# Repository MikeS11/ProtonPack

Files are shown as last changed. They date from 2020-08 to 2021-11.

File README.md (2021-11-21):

[][contributors-url]
[][forks-url]
[][stars-url]
[][issues-url]
[][license-url]
[][Twitter-url]

<!-- PROJECT LOGO -->
<br />
<p align="center">
  <a href="https://github.com/MikeS11/ProtonPack">
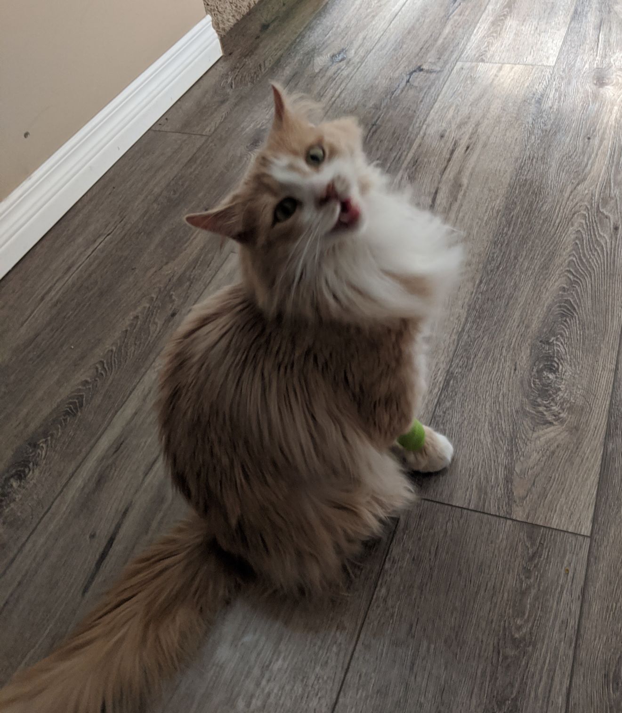
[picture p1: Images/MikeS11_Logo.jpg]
    
  </a>

  <h3 align="center">GhostKitty Proton Pack</h3>

  <p align="center">
  This is my contribution to the GB community. This project adds a bit more movie / game accuracy but also a little fun :)

<!-- TABLE OF CONTENTS -->
## Table of Contents

* [About the Project](#about-the-project)
  * [Built With](#Build-Requirements)
* [Getting Started](#getting-started)
  * [Prerequisites](#prerequisites)
  * [Wand Configuration](#wand-configuration)  
* [License](#license)
* [Contact](#contact)
* [Acknowledgements](#acknowledgements)

<!-- ABOUT THE PROJECT -->
## About The Project

<div align="center">
  YouTube Video<br /> 
  <a href="https://www.youtube.com/watch?v=9ePM4p-J3tE">GhostKitty Proton Pack</a>  
  
Original Prototype <br />
Prototype</p>

Afterlife Cyclotron 40 segment LED ring<br /> 
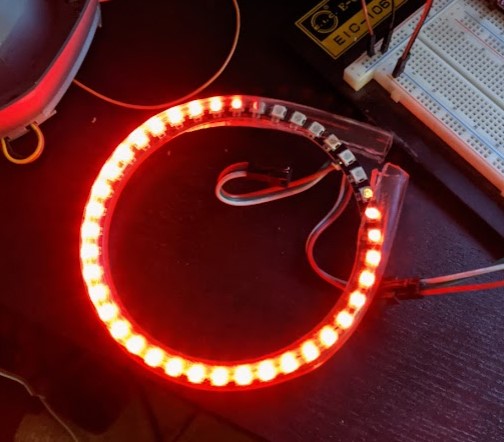
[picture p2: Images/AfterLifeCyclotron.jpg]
Prototype
</p>
</div>

I want this to be a source for anyone to use to create their own proton pack kits for as cheap as possible and still include all the features for a rumble motor, 2 firing mechanisms, all functioning LEDs in the wand, pack themes, full 28 segment bar graph, and an output for a vent kit.

**Current Themes for the pack:**
* []() Movie
* []() Stasis / Afterlife 
* []() Slime
* []() Meson
* []() Christmas!
* []() *Future* Halloween

### Getting Started

### Build Requirements:

* []() 1 - Arduino Nano (Amazon)  
* []() 1 - DFPlayer Mini (Be aware that some of the knock offs do not perform correctly, reference to the busy pin may not work) (Digikey Only)
* []() 1 - Any amplifing circuit (Currently testing an Adafruit Stereo 20W Class D Audio Amplifier - MAX9744)  (Amazon, Digikey)
* []() 1 - LED Matrix Driver - HT16K33 Breakout (for the bar graph) (Amazon, Digikey)
* []() 1 - 28 segment bargraph (barmeter.com, ebay is your best option)
* []() 1 - Pack of neopixels or equivalent WS2812B ( Vent and wand LEDs) (Amazon)
* []() 1 - LED strip (Powercell)  (Amazon)
* []() 1 - Adafruit Jewel - Wand Tip (WAs looking at the Pixie but there is a concern of its overhead requirements when working with normal WS2812B's, and they can not be chained together with WS2812B's) (Amazon, Digikey)
* []() 1 - 40 Segment LED ring or LED strip (WS2812B's) - Afterlife Cyclotron LED
* []() Pack of 24 awg stranded cable (Amazon) - To keep things clean you might want to look at ribbon cables or multi conductor cables. 
* []() For circuit noise filtering, I would add a 1000uF electrolytic capacitors closes to the neopixels, and a 470 Ohm resistor before the first led of the strip (This is recommended by Adafruit as well). I would recommend one 1000uF capacitor for the wand to filter out noise from both the bargraph and the neopixels. (See Diagram)
* []() If you are printing the PCB you will need a RJ45 Connector, 2.54mm JST Connectors, 2.54mm Dupont Connectors, 1 MP1584EN Buck Converter, 7805 Voltage regulator, 2 1k Ohm resistors, and some 0.1 uF and 0.33 uF ceramic capacitors. Additionally for the wand, 1000uF capacitor, a 1N4001 diode and a transistor.

### Prerequisites

You are going to need to install the following libraries:

**For the Audio DFPlayer Player:**
* []() SoftwareSerial.h
* []() DFPlayerMini_Fast.h

**For the WS2812B / NeoPixel LEDs**
* []() Adafruit_NeoPixel.h

**Custom Libraries for the Powercell / Cyclotron / Bargraph Animiations**
* []() GBLEDPatternsJewel.h
* []() BGSequence.h

**Sound Files for the DFPlayer or Alternative Player**

<a href="https://mega.nz/file/R5sWzCha#zm4DIskyvmF08JNp8MnOAEqCDmNe2MSCN6wtFMExKlU">Here are some sound files I found online or mixed myself</a>

### Wand Configuration

<p align="center">
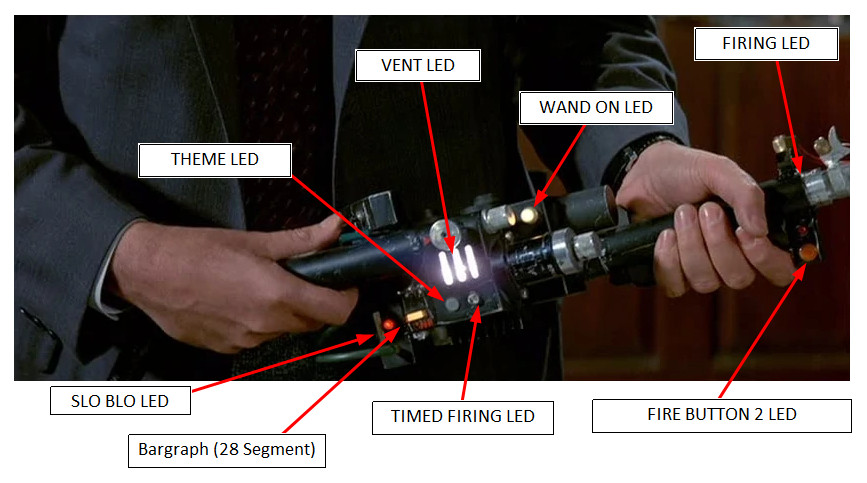
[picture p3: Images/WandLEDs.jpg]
Wand LEDs
</p>
<p align="center">
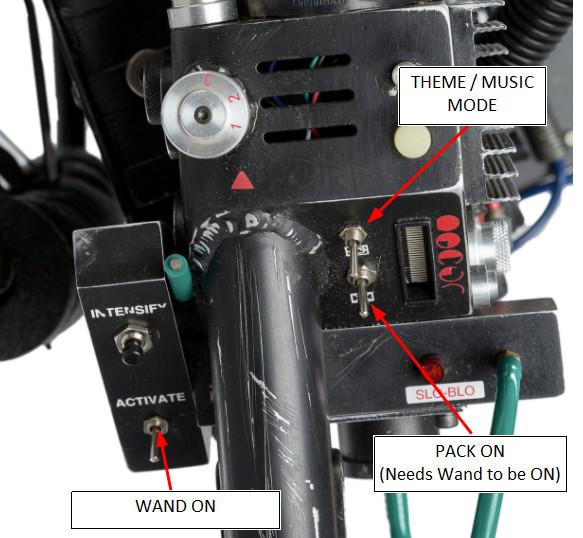
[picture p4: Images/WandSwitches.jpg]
Wand Switches
</p>
<!-- CONTRIBUTING -->
## Contributing

Contributions are what make the open source community such an amazing place to be learn, inspire, and create. Any contributions you make are **greatly appreciated**.

1. Fork the Project
2. Create your Feature Branch (`git checkout -b feature/AmazingFeature`)
3. Commit your Changes (`git commit -m 'Add some AmazingFeature'`)
4. Push to the Branch (`git push origin feature/AmazingFeature`)
5. Open a Pull Request

<!-- LICENSE -->
## License

Distributed under the MIT License. See `LICENSE` for more information.

<!-- CONTACT -->
## Contact

Mike Simone - [@mikesimone3](https://twitter.com/mikesimone3) 

Project Link: [https://github.com/MikeS11/ProtonPack](https://github.com/MikeS11/ProtonPack)

<!-- ACKNOWLEDGEMENTS -->
## Acknowledgements

* []() Eric Banker for the for the wonder work completed on his Arduino project. (a couple of his functions are referenced in this project) 
* []()
* []()

<!-- MARKDOWN LINKS & IMAGES -->
<!-- https://www.markdownguide.org/basic-syntax/#reference-style-links -->
[contributors-shield]: https://img.shields.io/github/contributors/MikeS11/ProtonPack.svg?style=flat-square
[contributors-url]: https://github.com/MikeS11/ProtonPack/graphs/contributors
[forks-shield]: https://img.shields.io/github/forks/MikeS11/ProtonPack.svg?style=flat-square
[forks-url]: https://github.com/MikeS11/ProtonPack/network/members
[stars-shield]: https://img.shields.io/github/stars/MikeS11/ProtonPack.svg?style=flat-square
[stars-url]: https://github.com/MikeS11/ProtonPack/stargazers
[issues-shield]: https://img.shields.io/github/issues/MikeS11/ProtonPack.svg?style=flat-square
[issues-url]: https://github.com/MikeS11/ProtonPack/issues
[license-shield]: https://img.shields.io/github/license/MikeS11/ProtonPack.svg?style=flat-square
[license-url]: https://github.com/MikeS11/ProtonPack/blob/master/LICENSE.txt
[twitter-shield]: https://img.shields.io/badge/-Twitter-black.svg?style=flat-square&logo=Twitter&colorB=555
[twitter-url]: https://Twitter.com/mikesimone3
[product-screenshot]: images/screenshot.png

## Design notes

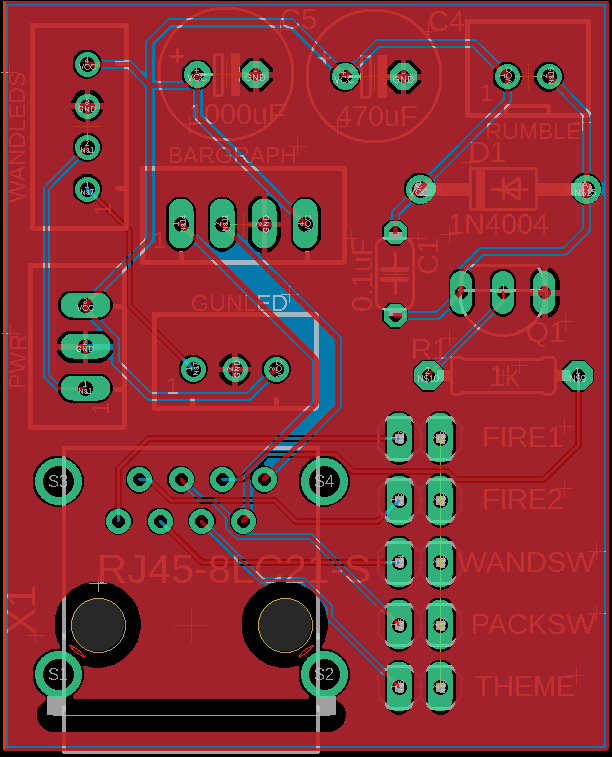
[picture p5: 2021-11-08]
Eagle PCB/WandPCB.png

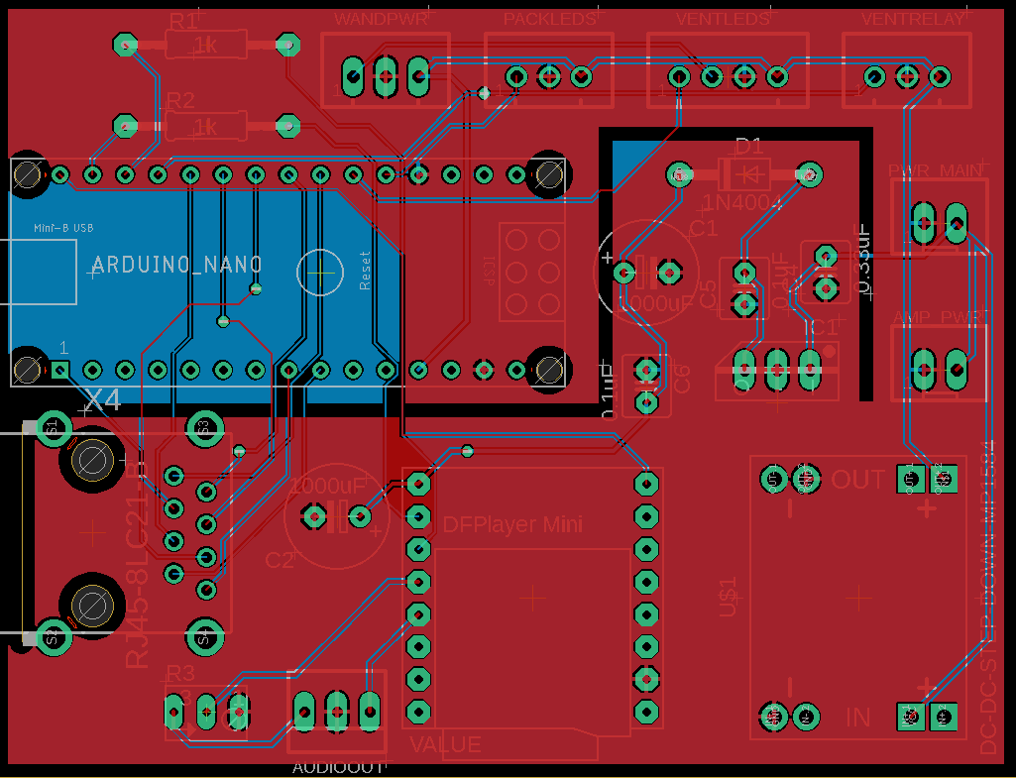
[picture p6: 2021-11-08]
Eagle PCB/PackPCB.png

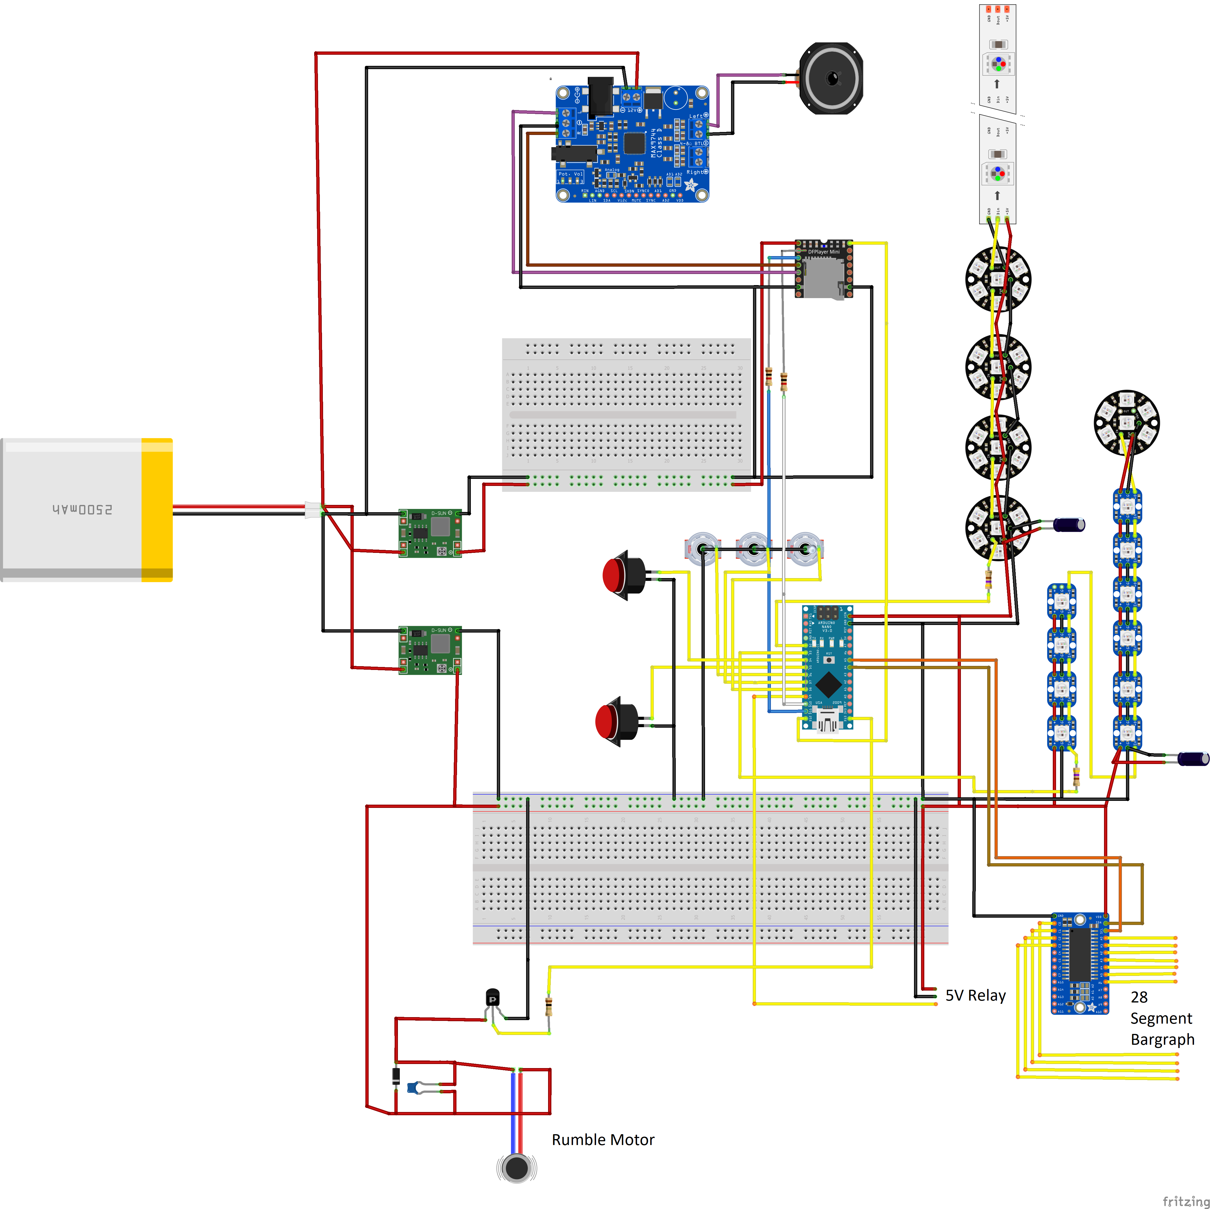
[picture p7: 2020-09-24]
Diagram/ProtonPack2020_bb1.png

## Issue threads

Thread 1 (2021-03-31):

Thanks! And a couple of small bargraph bugs...

prodestrian, 2021-03-31:
Hi! Found this repo on the Facebook Group a while back and finally getting around to doing some of the pack electronics.

I started writing a library to handle a 28-segment bargraph controlled by a HT16K33 when I remembered you'd basically already done all the work, so I brought yours in and I've started testing it. So far so good, you've easily saved me days of work here, so thankyou! :smile:

Just a couple of little things I noticed...

https://github.com/MikeS11/ProtonPack/blob/ab19a8d30ab484f0a8a88561ca24bb286b1c2d76/Source/Libraries/GB_Bargraph_Sequence/BGSequence.cpp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
In my local copy of the library, I've modified this so that the address can be passed in. My breakout board is actually on `0x72` (because it's salvaged from another project and I haven't yet desoldered the jumper), so this lets me control it from outside the library:
```c++
void BGSequence::BGSeq(uint8_t addr)
{
  /*
     Initiate the HT16K33
  */
  bargraph.init(addr);
```

https://github.com/MikeS11/ProtonPack/blob/ab19a8d30ab484f0a8a88561ca24bb286b1c2d76/Source/Libraries/GB_Bargraph_Sequence/BGSequence.cpp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
The sequenceStart animation causes my 28th pixel to flash for just a second before the animation starts at the other end. Changing `IndexSegment` from `27` to `0` seems to fix it.

https://github.com/MikeS11/ProtonPack/blob/ab19a8d30ab484f0a8a88561ca24bb286b1c2d76/Source/Libraries/ht16k33-arduino-master/HT16K33.cpp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
I noticed that on startup/reset random pixels on the bargraph would flash for a split second, so I borrowed the code from the Adafruit LEDBackpack library which resets the "garbage" before turning the LEDs on. Problem solved!
```c++
  // internal RAM powers up with garbage/random values.
  // ensure internal RAM is cleared before turning on display
  // this ensures that no garbage pixels show up on the display
  // when it is turned on.
  clear();
  write();

  // set blink off + brightness all the way up
  setBlink(HT16K33_BLINK_OFF);
  setBrightness(15);
```

https://github.com/MikeS11/ProtonPack/blob/ab19a8d30ab484f0a8a88561ca24bb286b1c2d76/Source/Libraries/GB_Bargraph_Sequence/BGSequence.cpp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
I changed this to just use the HT16K33 `clear()` function which does basically the same thing.
```c++
void BGSequence::clearLEDs()
{
  bargraph.clear();
  bargraph.write();
}
```

That's all I have for now, I may end up forking and refactoring the code to fit better in my project's codebase, but if I get a chance I'll see if I can submit a PR at the same time. I can also see some room for simplification around the place, but we'll see if I get time to look into it.

Thanks again for releasing this! :grin: :trophy:

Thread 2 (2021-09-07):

What exactly is this 5v relay used for in the diagram on the bottom right next to the bargraph? Thanks!

ytineres, 2021-09-07:

MikeS11, 2021-09-07:
It's used for an expandable smoke kit and triggers a relay to power it's
operation.

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

ytineres, 2021-09-07:
Thanks so much! saves me a step of adding it in later.

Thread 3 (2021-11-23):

28 segment bargraph help

seansz28, 2021-11-23:
is there a diagram how to solder the 28 segment bar graph to the breakout board

semix79, 2022-03-17:
I have Problems to run the Bargraph. I soldered like in the Youtube Video from Wholesome Joe. But it doesn´t fuction. Do i must chance something in the Code? I tested with different Arduino nanos, and 2 different ht16k33 Chips. No function from the Bargraph. The Bargraph Leds are okay.

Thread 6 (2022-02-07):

aiuto

nonsochenomemettere1111111, 2022-02-07:
Ciao Mike , mi piacerebbe usare il tuo progetto e volevo chiederti i file audio vanno messi tutti su sd card ? è da rispettare l'ordine che hai postato ? i due pulsanti a cosa servono? e possibile caricare ache la canzone di ghostbusters ? se si come ?

nonsochenomemettere1111111, 2022-02-13:
Dal video di mikes11 sembra che funziona !!! Come mai ?

semix79, 2022-02-13:
I find something out. What size of sd card do you Use? With a 2gb card the songs work.  Use  001, 002, 003, 004 and so on for the numbers in the 01 folder. But the issue with the Sound is still there :(

nonsochenomemettere1111111, 2022-02-13:
Uso una sd da 2gb  .... infatti le canzoni funzionano anche a me... ma gi effetti compreso quello dello stato non funziona .... come si cambiano le modalità film, christmas ecc... ?

semix79, 2022-02-17:
I have solved the Problem! It realy depends on the dfplayer! You need the one who is manufactured by dfrobot! Then it works perfect! I tested 4 different chips. Only the dfrobot works.

nonsochenomemettere1111111, 2022-02-17:
Puoi mandarmi il link per acquistare quello giusto?

semix79, 2022-02-17:
Digikey.de

nonsochenomemettere1111111, 2022-02-17:
Grazie   grazie

nonsochenomemettere1111111, 2022-02-23:
Grazie all'aiuto di semix79  ho risolto anche  io ,montando dfplayer mini originale df roboot ...una domanda a semix79... le canzoni che si possono aggiungere vanno messe nel formato mp3 nella cartella 01 ? Perché mi succede che se le metto sulla cartella 01 come accendo esegue subito brani mp3 .... qli effetti vanno lasciati nella cartella mp3 ?  Grazie in anticipo per il tuo aiuto ....

semix79, 2022-02-23:
Gerne. :) Es ist egal ob mp3 oder wav. Die Trackbeschriftung hast du richtig? Dreistellig bei den Songs und Vierstellig bei den Effekten im mp3 ordner. Lösche mal die Sd Karte und spiele alles noch einmal gleichzeitig auf die Karte.

nonsochenomemettere1111111, 2022-02-23:
Ok ok .. non avevo capito... quindi la cartella 01 può essere cancellata o lasciata vuota ?

semix79, 2022-02-23:
In den 01 ordner kommen die Lieder

nonsochenomemettere1111111, 2022-02-23:
Ok grazie grazie  del tempo dedicato lo zaino protonico come l'hai realizzato con stampante 3d ? Il progetto dove l'hai preso ?

nonsochenomemettere1111111, 2022-02-27:
Quali sono le funzioni specifiche degli interruttori e dei pulsanti ? C'è xuna sequenza di accensione da rispettare ? Come metto  i file audio rinominandoli in 001,002 ecc vengono riprodotti come accendo ... perché?

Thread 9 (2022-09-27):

Error in trace placement on pack PCB

GForce2010, 2022-09-27:
Firstly, thanks for sharing your designs and code, very helpful.

I've just downloaded the PCB files and when I was trying to work out how everything connected on the board I found that two traces appear to be overlapping.

The trace from D2 to PackLEDA is overlapping with the trace from D9 to VentRelayA just below he WANDPWR terminal block.

meltman, 2022-09-27:
If you correct the issues, mind exporting gerber files and doing a PR? Lol, looks like halloween is on the horizon.

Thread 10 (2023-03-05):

fuzzy on some details (pcb)

tankboyben, 2023-03-05:
hi, where does the power go into the board? is it near audio (R3)? and is it 12v?

secondly what connectors should be on audio and R3?

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

MikeS11, 2023-03-05:
Power should go into power main (Make sure your buck converter is
outputting 5V before you plug in your controller), and you can use the same
12V rail to output to an external 12V amp (AMP PWR) for your speaker as
well.  I should have made it more clear around R3 but R3 is for a
potentiometer for volume control. And The two left pin then are used for
Audio Out.

Hope that helps!

[image: image.png]

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

tankboyben, 2023-03-05:
amazing, thank you :)

tankboyben, 2023-05-01:
just wanted to add that your board didnt work unfortunately, the updated one by the other chap did, however on both yours and theirs, all the connectors are the wrong way round and will result in blowing up various components if things are plugged in in those orientations

MikeS11, 2023-05-01:
If you can be more specific it would be helpful. I've been using the design for a couple years now and everything works fine.

lockenschmuggler, 2023-08-14:
Hi MikeS11,
planning to order a pcb. Right now I am adjusting the eagle files to fit properly for KiCad.
Therefore: Is there a chance for you to make a pic of your Powerpack and Wand PCBs? Would be appreciated.
thus, since I have still some question-marks with regards to the pcb-layout.
E.g.: there is a build-in potentionmeter. If I use an amp, this seems somehow redundant (maybe this is due to my lack of understanding). Same with audio out: Is this to be connected with the amp or with the boxes?
As said before: support appreciated...

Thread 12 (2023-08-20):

Relay Issues

GrgorOHart, 2023-08-20:
I'm having an issue with my 5v relay turning on when battery power is turned on. Then the relay won't shut off until I turn the wand on. If I have the wand on when I turn power on, the relay fires for about 1 second then shuts off and then functions properly. I'm using an Arduino Nano and a Hiletgo 5v relay. The relay is powered by 5v usb from the Talentcell. When I volt test the signal wire to the relay, I'm getting about 3.8v, which is normal for a Nano. Is there a specific relay I should use of something in the code I need to update? Thank you in advance!

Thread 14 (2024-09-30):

Some issues (mostly user related :D) and questions

NvdGoorbergh, 2024-09-30:
Hi Mike,

I am trying to replicate this awesome piece of code but I am running into some issues.
I tried locating your cointact details but couldn't find one other then you twitter handle and I removed myself from twitter quite a while ago.

So the first question that I have is do you have the arduino in the pack and run that many wires to the wand or is it vice versa?
My pack is almost ready (am still waiting on some parts) and would love to have this ready by the end of next month but that is still something that I can't find :D.

The second question seems to be an user error. But I have some trouble with getting the dfplayer to work. The moment I connect the busy pin to the arduino the arduino goes on and the dfplayer goes off. I got the bare dfplayer code working last night so I will try to incoorporate that with your code again and hopefully it starts working.
I also have the 20w amp but that one gives me more headaches than joy :D. There is a 12v battery pack on the way and I hope that will solve a few of my issues there.

I tried going trough the code and the files and there is not a music mode built in right? I decided to go with your code because I love the video game options and had more than half of the parts already. annyhow, thank you so much for your work. Is there a way to donate a cup of coffe or something? Let me know! With kind regards,
Nick

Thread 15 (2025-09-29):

Wand PCB: Switches not connected to ground

octalthorpe, 2025-09-29:
I printed out the mainboard and wand board, but after placing all the components, noticed that the switches do not function.  The Arduino inputs are always high.

I believe there are two problems, firstly the switch pins on the non Arduino side are not all bonded together.
And second the are not connect to ground.

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

According to the schematic the pins are joined together, however after printing the PCB, they are actually isolated, maybe something Eagle optimizes out.

I can easily work around the issue bonding them and then pulling them to ground, so when switches are closed they will pull the inputs to ground on the wand power input.

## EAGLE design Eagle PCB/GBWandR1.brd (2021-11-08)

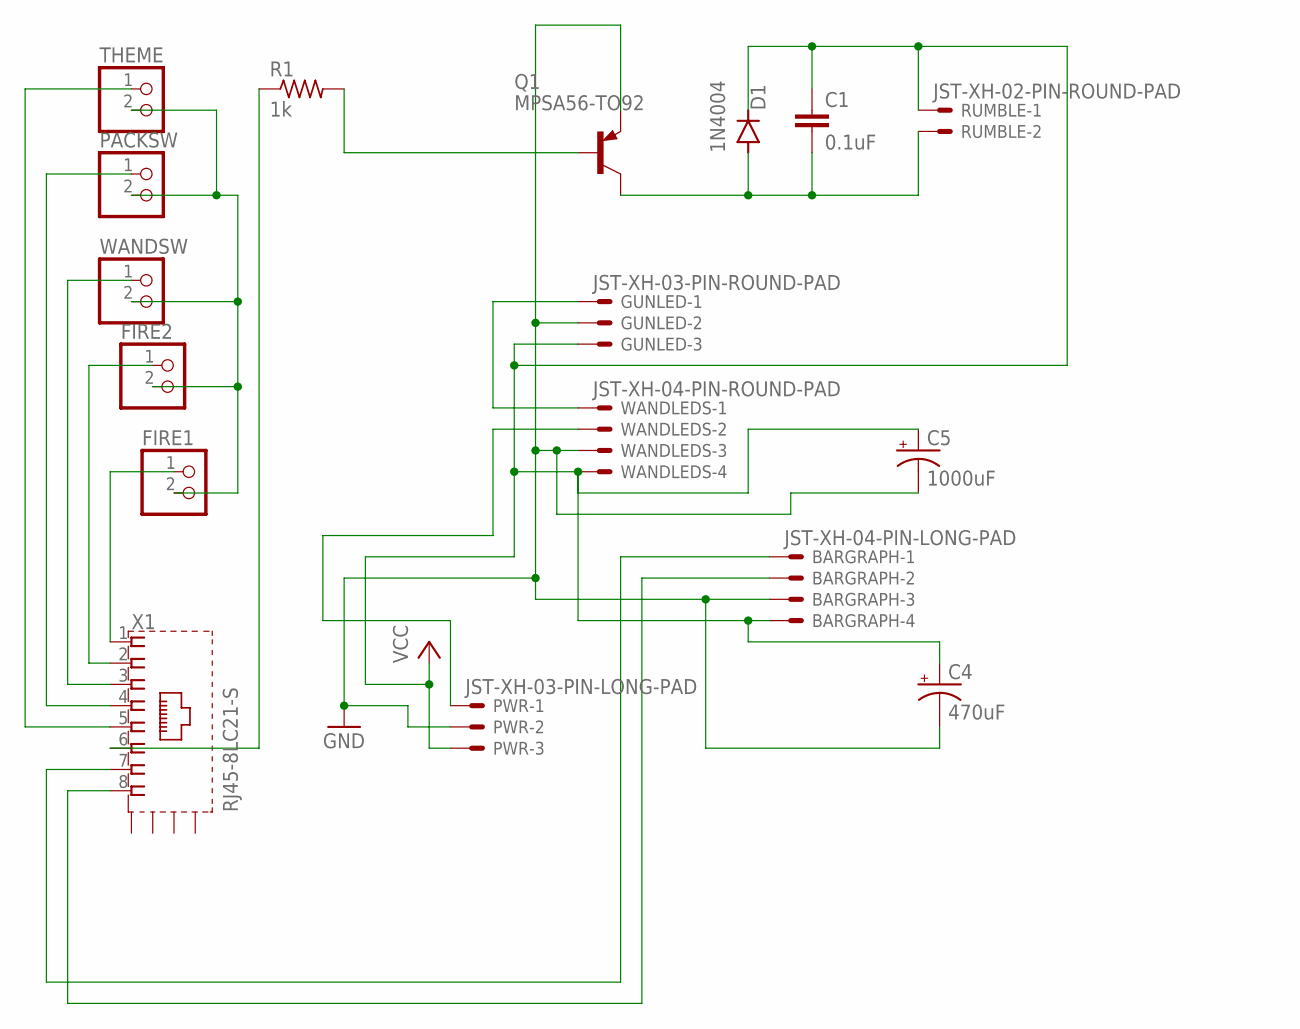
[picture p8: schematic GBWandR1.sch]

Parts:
BARGRAPH: JST-XH-04-PIN-LONG-PAD; JST-XH-04-PACKAGE-LONG-PAD
C1: 0.1uF; C050-024X044
C4: 470uF; E3,5-8
C5: 1000uF; E3,5-8
D1: 1N4004; DO41-10
FIRE1, FIRE2: PINHD-1X2; 1X02
GUNLED: JST-XH-03-PIN-ROUND-PAD; JST-XH-03-PACKAGE-ROUND-PAD
PACKSW: PINHD-1X2; 1X02
PWR: JST-XH-03-PIN-LONG-PAD; JST-XH-03-PACKAGE-LONG-PAD
Q1: MPSA56-TO92; TO92-CBE
R1: 1k; 0207/9
RUMBLE: JST-XH-02-PIN-ROUND-PAD; JST-XH-02-PACKAGE-ROUND-PAD
THEME: PINHD-1X2; 1X02
WANDLEDS: JST-XH-04-PIN-ROUND-PAD; JST-XH-04-PACKAGE-ROUND-PAD
WANDSW: PINHD-1X2; 1X02
X1: RJ45-8LC21-S; RJ45-SHIELD1

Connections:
GND: BARGRAPH.3, C4.-, C5.-, GUNLED.2, PWR.2, Q1.E, WANDLEDS.3
unnamed: PWR.1, WANDLEDS.2
unnamed: FIRE1.1, X1.1
unnamed: FIRE2.1, X1.2
unnamed: WANDSW.1, X1.3
unnamed: PACKSW.1, X1.4
unnamed: THEME.1, X1.5
unnamed: GUNLED.1, WANDLEDS.1
unnamed: FIRE1.2, FIRE2.2, PACKSW.2, THEME.2, WANDSW.2
unnamed: R1.1, X1.6
unnamed: Q1.B, R1.2
unnamed: BARGRAPH.2, X1.8
unnamed: BARGRAPH.1, X1.7
unnamed: C1.2, D1.A, Q1.C, RUMBLE.2
VCC: BARGRAPH.4, C1.1, C4.+, C5.+, D1.C, GUNLED.3, PWR.3, RUMBLE.1, WANDLEDS.4

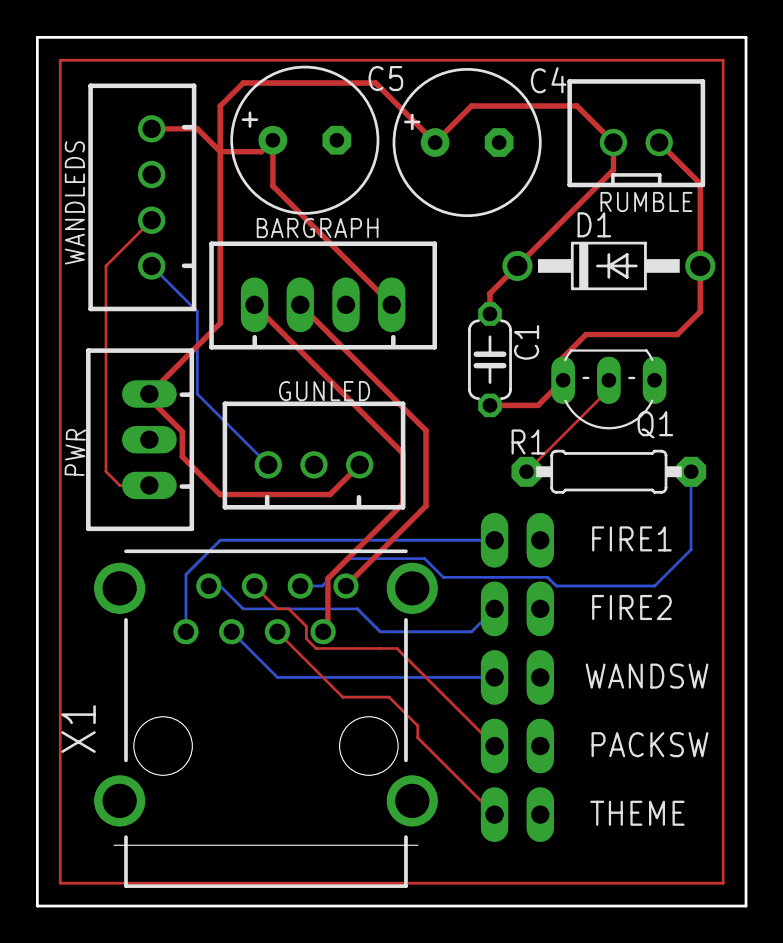
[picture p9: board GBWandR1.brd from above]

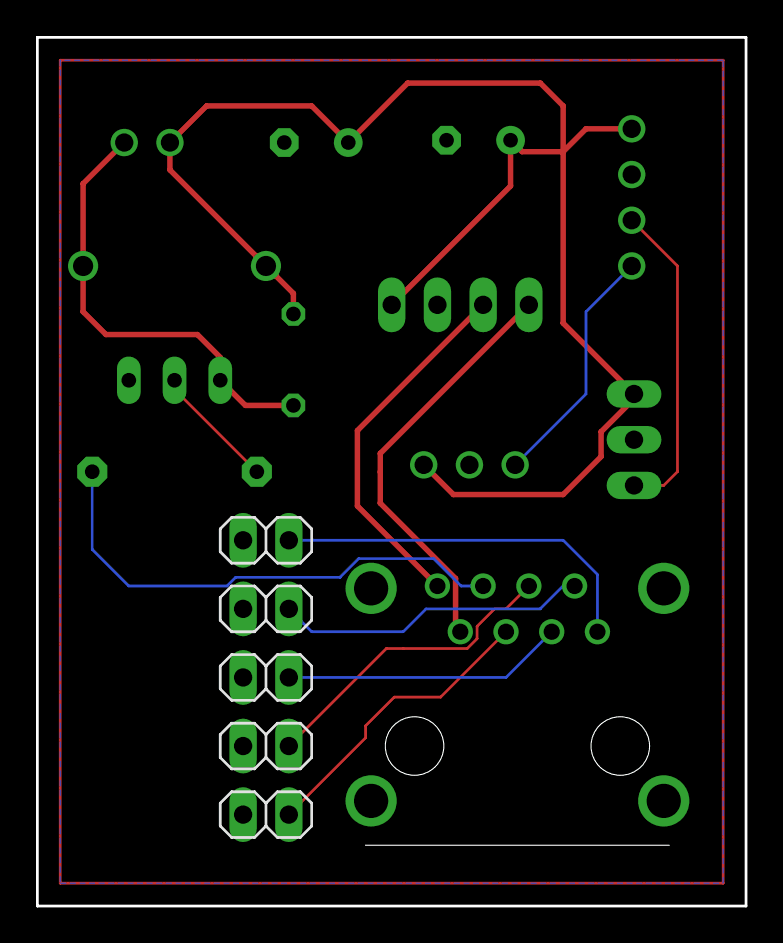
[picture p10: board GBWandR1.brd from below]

Board: 2 copper layers, 39.4 x 48.3 mm, 17 parts (5 on the bottom side), 15 nets.

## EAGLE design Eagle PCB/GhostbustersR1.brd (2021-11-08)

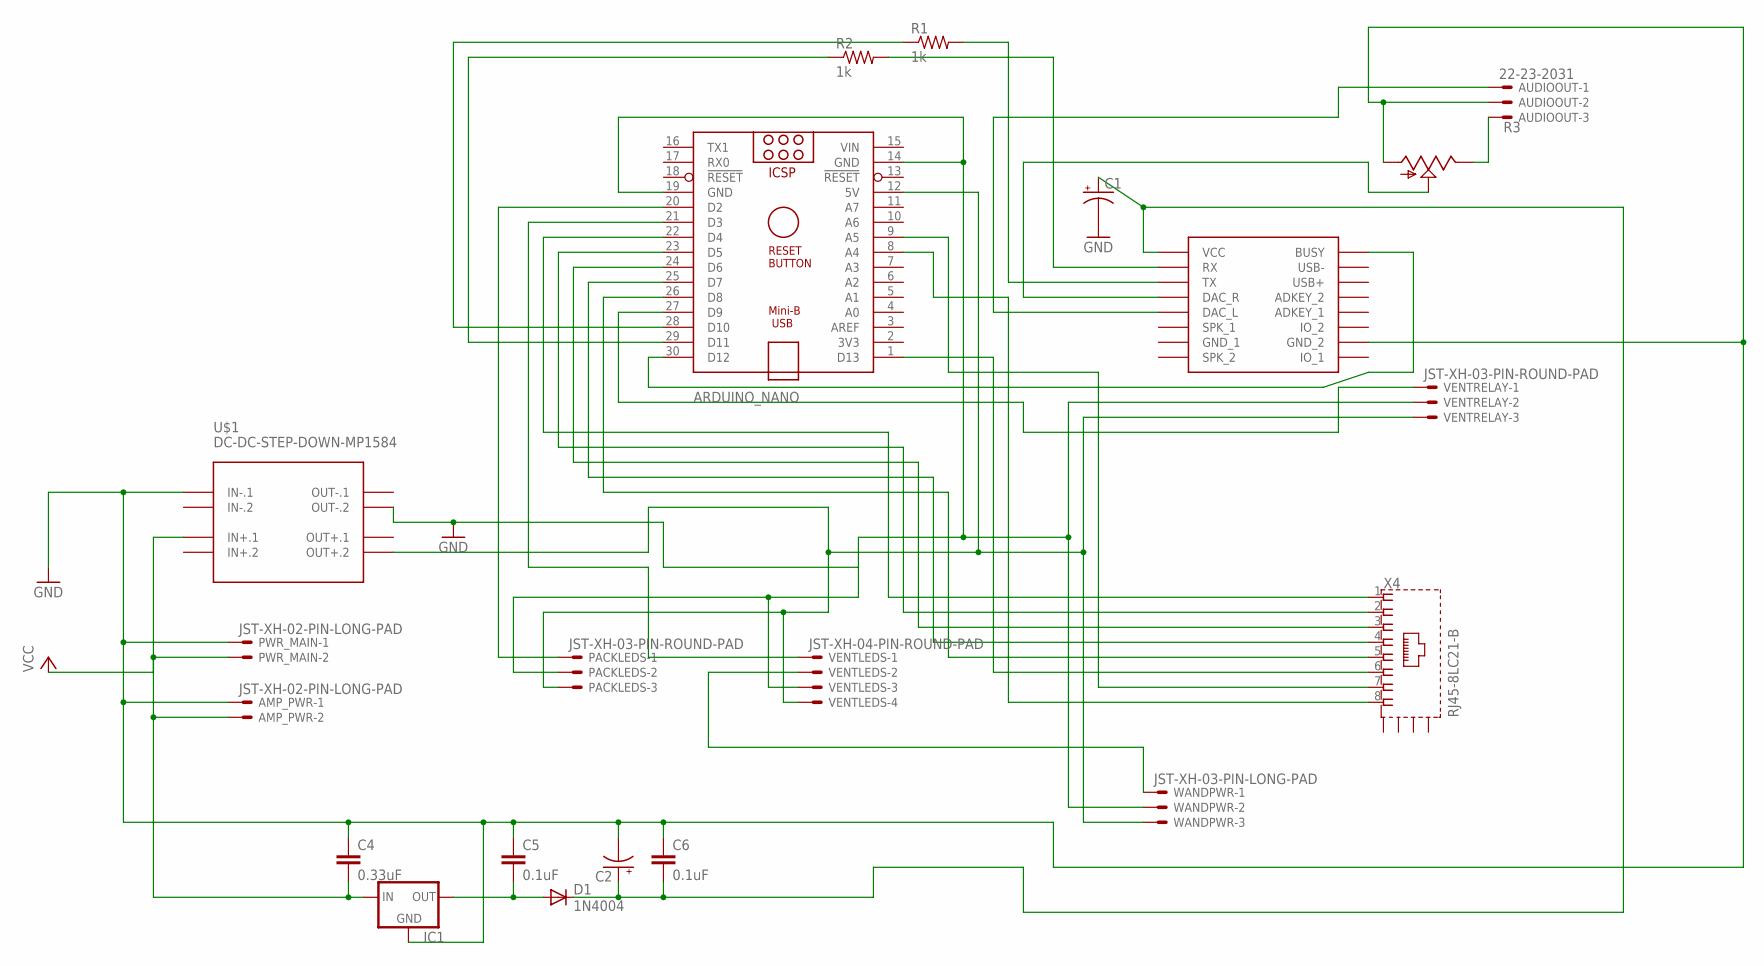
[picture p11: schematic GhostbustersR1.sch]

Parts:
AMP_PWR: JST-XH-02-PIN-LONG-PAD; JST-XH-02-PACKAGE-LONG-PAD
ARDUINO_NANO: ARDUINO_NANO
AUDIOOUT: 22-23-2031
C1, C2: CPOL-USE3.5-8; E3,5-8
C4: 0.33uF; C2.5-4
C5, C6: 0.1uF; C2.5-4
D1: 1N4004; DO41-10
DFPLAYER: DFPLAYER
IC1: 78MXXS
PACKLEDS: JST-XH-03-PIN-ROUND-PAD; JST-XH-03-PACKAGE-ROUND-PAD
PWR_MAIN: JST-XH-02-PIN-LONG-PAD; JST-XH-02-PACKAGE-LONG-PAD
R1, R2: 1k; 0207/12
R3: TRIM_US-B64Y; B64Y
U$1: DC-DC-STEP-DOWN-MP1584
VENTLEDS: JST-XH-04-PIN-ROUND-PAD; JST-XH-04-PACKAGE-ROUND-PAD
VENTRELAY: JST-XH-03-PIN-ROUND-PAD; JST-XH-03-PACKAGE-ROUND-PAD
WANDPWR: JST-XH-03-PIN-LONG-PAD; JST-XH-03-PACKAGE-LONG-PAD
X4: RJ45-8LC21-B; RJ45-SHIELD1

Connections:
GND: AMP_PWR.1, ARDUINO_NANO.14 (GND), ARDUINO_NANO.19 (GND), AUDIOOUT.2, C1.-, C2.-, C4.1, C5.1, C6.1, DFPLAYER.GND_2, IC1.GND, PACKLEDS.2, PWR_MAIN.1, R3.A, U$1.IN-.1, U$1.OUT-.2, VENTLEDS.3, VENTRELAY.2, WANDPWR.2
unnamed: ARDUINO_NANO.12 (5V), PACKLEDS.3, U$1.OUT+.2, VENTLEDS.4, VENTRELAY.3, WANDPWR.3
unnamed: ARDUINO_NANO.25 (D7), X4.4
unnamed: AUDIOOUT.3, R3.E
unnamed: ARDUINO_NANO.29 (D11), R2.1
unnamed: ARDUINO_NANO.28 (D10), R1.1
unnamed: ARDUINO_NANO.20 (D2), PACKLEDS.1
unnamed: ARDUINO_NANO.21 (D3), VENTLEDS.1
unnamed: VENTLEDS.2, WANDPWR.1
unnamed: ARDUINO_NANO.22 (D4), X4.1
unnamed: ARDUINO_NANO.23 (D5), X4.2
unnamed: ARDUINO_NANO.24 (D6), X4.3
unnamed: ARDUINO_NANO.26 (D8), X4.5
unnamed: ARDUINO_NANO.1 (D13), X4.6
unnamed: ARDUINO_NANO.30 (D12), DFPLAYER.BUSY
unnamed: DFPLAYER.DAC_R, R3.S
unnamed: AUDIOOUT.1, DFPLAYER.DAC_L
unnamed: ARDUINO_NANO.27 (D9), VENTRELAY.1
unnamed: ARDUINO_NANO.8 (A4), X4.8
unnamed: ARDUINO_NANO.9 (A5), X4.7
unnamed: DFPLAYER.TX, R1.2
unnamed: DFPLAYER.RX, R2.2
unnamed: C5.2, D1.A, IC1.OUT
unnamed: C1.+, C2.+, C6.2, D1.C, DFPLAYER.VCC
VCC: AMP_PWR.2, C4.2, IC1.IN, PWR_MAIN.2, U$1.IN+.1
VIN: ARDUINO_NANO.15 (VIN)

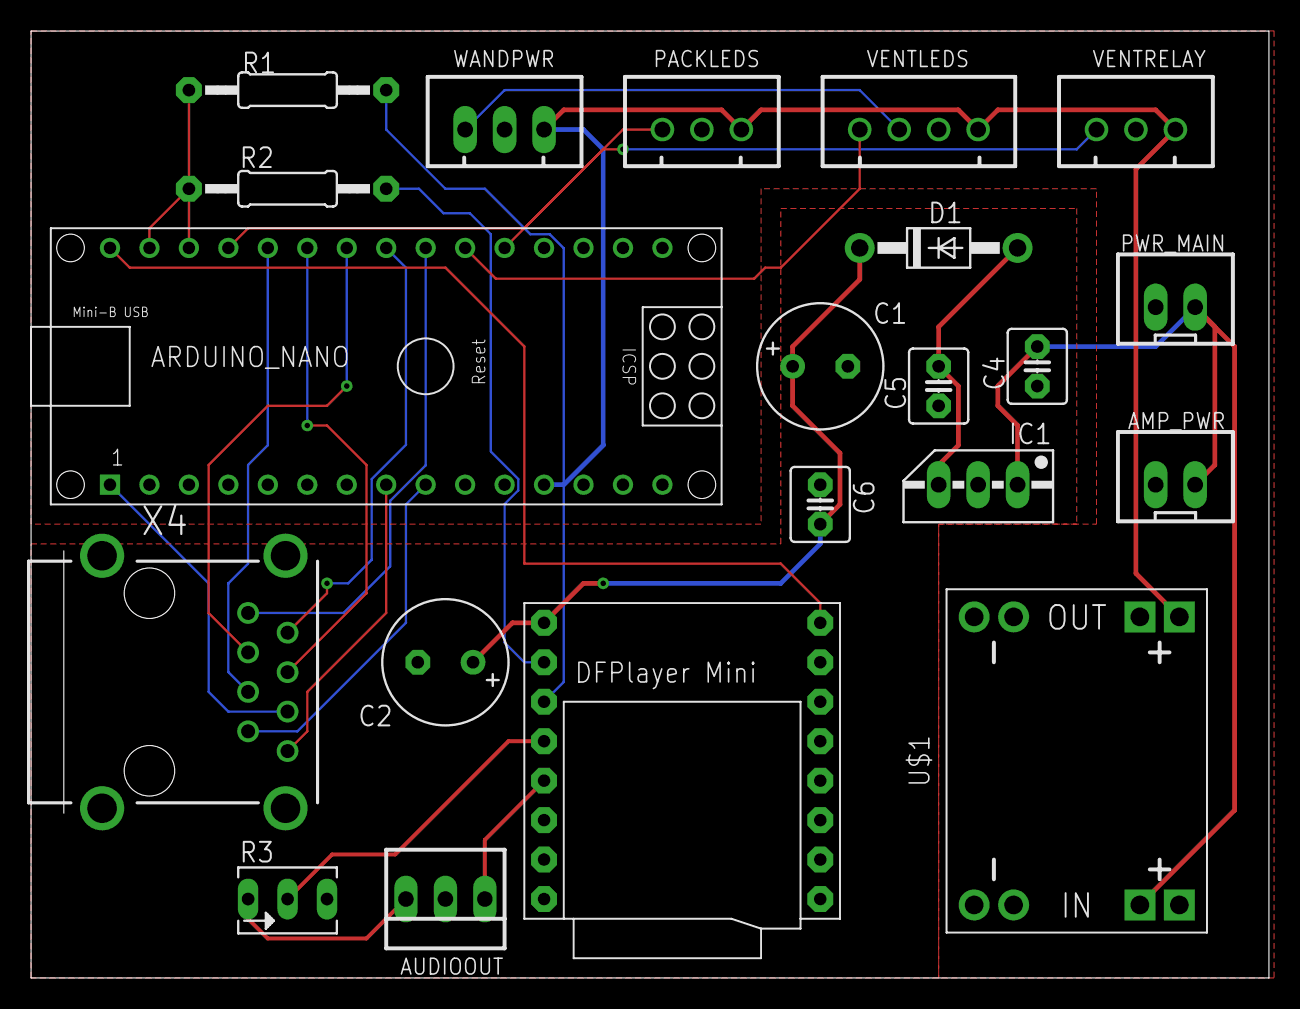
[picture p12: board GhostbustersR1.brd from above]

Board: 2 copper layers, 79.7 x 60.9 mm, 21 parts (0 on the bottom side), 25 nets.

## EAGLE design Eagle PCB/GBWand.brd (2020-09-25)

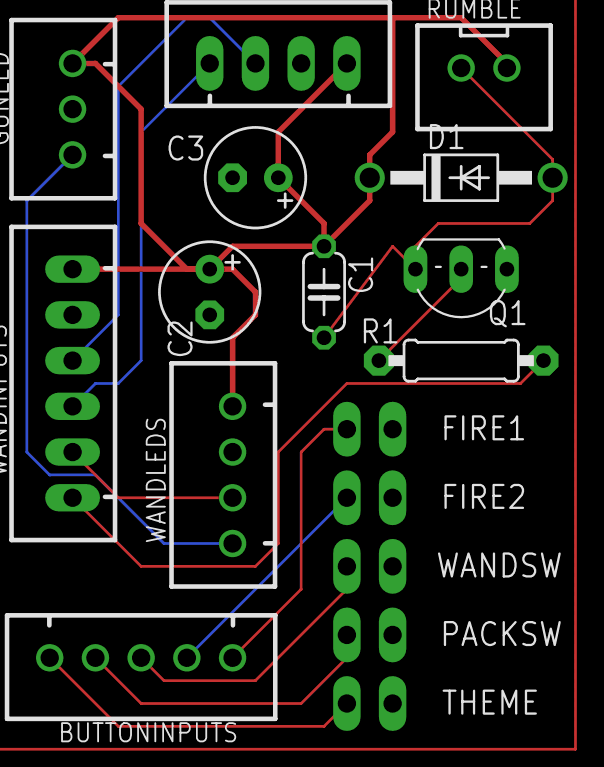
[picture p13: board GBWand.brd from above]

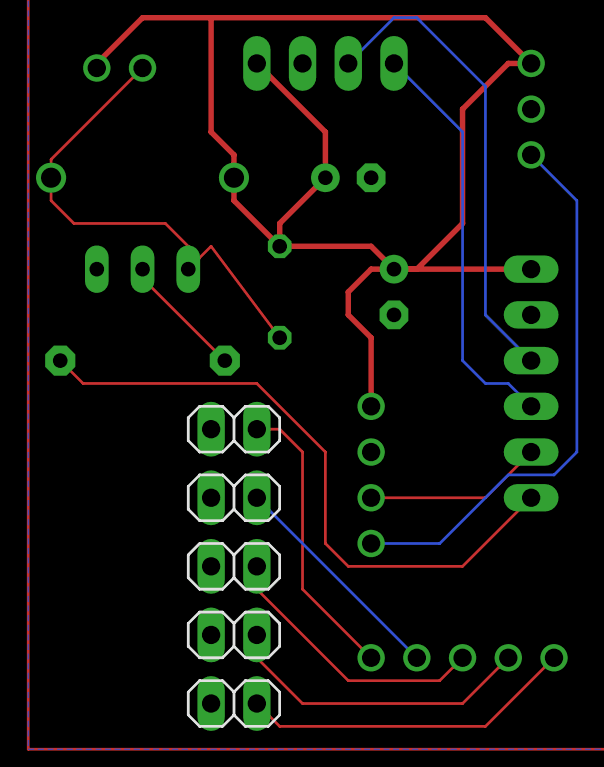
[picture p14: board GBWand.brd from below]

Board: 2 copper layers, 17 parts (5 on the bottom side), 14 nets.

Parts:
BARGRAPH: JST-XH-04-PIN-LONG-PAD; JST-XH-04-PACKAGE-LONG-PAD
BUTTONINPUTS: JST-XH-05-PIN-ROUND-PAD; JST-XH-05-PACKAGE-ROUND-PAD
C1: 0.1uF; C050-024X044
C2: 1000uF; E2,5-6
C3: 470uF; E2,5-6
D1: 1N4004; DO41-10
FIRE1, FIRE2: 1X02
GUNLED: JST-XH-03-PIN-ROUND-PAD; JST-XH-03-PACKAGE-ROUND-PAD
PACKSW: 1X02
Q1: MPSA56-TO92; TO92-CBE
R1: 1k; 0207/9
RUMBLE: JST-XH-02-PIN-ROUND-PAD; JST-XH-02-PACKAGE-ROUND-PAD
THEME: 1X02
WANDINPUTS: JST-XH-06-PIN-LONG-PAD; JST-XH-06-PACKAGE-LONG-PAD
WANDLEDS: JST-XH-04-PIN-ROUND-PAD; JST-XH-04-PACKAGE-ROUND-PAD
WANDSW: 1X02

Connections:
GND: BARGRAPH.3, C2.-, C3.-, FIRE1.2, FIRE2.2, GUNLED.2, PACKSW.2, Q1.E, THEME.2, WANDINPUTS.5, WANDLEDS.3, WANDSW.2
unnamed: WANDINPUTS.2, WANDLEDS.2
unnamed: BUTTONINPUTS.1, FIRE1.1
unnamed: BUTTONINPUTS.2, FIRE2.1
unnamed: BUTTONINPUTS.3, WANDSW.1
unnamed: BUTTONINPUTS.4, PACKSW.1
unnamed: BUTTONINPUTS.5, THEME.1
unnamed: GUNLED.1, WANDLEDS.1
unnamed: R1.1, WANDINPUTS.1
unnamed: Q1.B, R1.2
unnamed: BARGRAPH.2, WANDINPUTS.4
unnamed: BARGRAPH.1, WANDINPUTS.3
unnamed: C1.2, D1.A, Q1.C, RUMBLE.2
VCC: BARGRAPH.4, C1.1, C2.+, C3.+, D1.C, GUNLED.3, RUMBLE.1, WANDINPUTS.6, WANDLEDS.4

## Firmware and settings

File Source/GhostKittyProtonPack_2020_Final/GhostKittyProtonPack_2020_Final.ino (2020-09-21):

/****************************************************************************************
   Michael Simone - Arduino Source for 2020 Ghostbusters Proton Pack
   LED pinout 2 / 3 using addressable LED's (NewPixels) and 1 Adafruit Jewel for the wand gun (Will look to upgrade it to a Pixie in the future)
   Pinout 2 - Cyclotron LEDs 0 - 19, Powercell, 20 - 35
   Pintout 3 - Cyclotron Vent 0 - 3, 4 Slow-Blow, 5 Wand Vent, , 6 White LED, 7 White LED2, 8, Yellow LED, , 9 Orange Hat LED, 10-16 NeoPixel Jewel 
   Sound Module - DFPlayer
   Some Reference Code from Eric Banker (Wand LED write helper function)
******************************************************************************************/


/*********************************************************
    Initiate Libraries for the 28 segment bargraph
 *********************************************************/

#include <BGSequence.h>
BGSequence BarGraph;

// **** Different Bargraph sequence modes **** //
enum BarGraphSequences { START, ACTIVE, FIRE1, FIRE2, BGVENT };
BarGraphSequences BGMODE;

/*********************************************************
    Initiate Libraries for DFPlayer sound module
 *********************************************************/

#include "SoftwareSerial.h"
#include <DFPlayerMini_Fast.h>

SoftwareSerial mySoftwareSerial(10, 11); // RX, TX
DFPlayerMini_Fast myDFPlayer;

// *** Audio Tracks - Note DFPlayer is sensitive to file order *** //
unsigned long  StartupTrack = 1;
unsigned long  ThemeSWTrack = 3;
unsigned long  SlimeSWTrack = 32;
unsigned long  MesonSWTrack = 31;
unsigned long  ChristmasSWTrack = 26;

unsigned long  FireMovie = 11;
unsigned long  FireCrossStreams = 12;
unsigned long  FireStasis = 13;
unsigned long  FireSlime = 14;
unsigned long  FireMeson = 15;
unsigned long  FireChristmas = 21;

unsigned long  MovieTail = 4;
unsigned long  StasisTail = 22;
unsigned long  SlimeTail = 23;
unsigned long  MesonTail = 24;
unsigned long  ChristmasTail = 25;

unsigned long  shutdownTrack = 10;
unsigned long  IdleMovieStart = 5;
unsigned long  IdleMovieLoop = 2;
unsigned long  IdleSlimeStart = 27;
unsigned long  IdleSlimeLoop = 28;
unsigned long  IdleMesonStart = 29;
unsigned long  IdleMesonLoop = 30;

unsigned long  clickTrack = 8;
unsigned long  chargeTrack = 7;
unsigned long  ventTrack = 9;
unsigned long  SlimeRefillTrack = 33;

unsigned long  warnMovie = 16;
unsigned long  warnStasis = 17;
unsigned long  warnSlime = 18;
unsigned long  warnMeson = 19;
unsigned long  warnCrossStreams = 20;

/*************************************************************************
    Initiate LED Variables
*************************************************************************/
int seq_1_current = 0;  // current led in sequence 1
const int num_led = 15; // total number of leds in bar graph
unsigned long firing_interval = 40;     // interval at which to cycle firing lights on the bargraph. We update this in the loop to speed up the animation so must be declared here (milliseconds).

const int ventStart = 0;              // Pack Vent LED's 0 - 3
const int ventEnd = 3;
const int SloBloLED = 4;              // Slo Blo LED
const int WandVentLED = 5;            // Wand Vent LED
const int ThemeLED = 6;               // Wand Theme LED
const int WhiteLED1 = 7;              // Wand "Is Firing" strobe LED
const int WhiteLED2 = 8;              // Wand On LED
const int OrangeHatLED = 9;           // Wand Fire Button 2 LED
const int GunLEDStart = 10;           // Wand Gun LED's 10 - 16
const int GunLEDEnd = 16;             

/******************************************************************************
    Initiate Adafruit LED NeoPixel libraries and custom GBLEDPattern Class
 ******************************************************************************/

#include <Adafruit_NeoPixel.h>
#include <GBLEDPatternsJewel.h>

// *** Note these constants may change if you are using different LED counts, E.g. 1 LED vs a 7 LED Neopixel Jewel *** //

// Cyclotron + PowerCell LED Count
const int NeoPixelLEDCount1 = 44;

// Vent + Wand LED Count
const int NeoPixelLEDCount2 = 17;

void PackLEDsComplete();

#define NEO_WAND 3 // for powercell
Adafruit_NeoPixel wandLights = Adafruit_NeoPixel(NeoPixelLEDCount2, NEO_WAND, NEO_GRB + NEO_KHZ800);

// Call Cyclotron Patterns Class
NeoPatterns PackLEDs(NeoPixelLEDCount1, 2, NEO_GRB + NEO_KHZ800, &PackLEDsComplete);

// ******************* Pack Status / State Arrays ******************* //
enum PackState { OFF, BOOTING, BOOTED, POWERDOWN };
enum PackState STATUS;

enum WandState { WANDOFF, ON, ON_PACK };
enum WandState WANDSTATUS;

enum WandSLEDState { ALLOFF, WANDONLY, NORMAL, FIRING, WARNING, FASTWARNING, VENTSTATE, STREAMCROSS };
enum WandSLEDState WANDLEDSTATUS;

enum PackTheme { MOVIE, STASIS, SLIME, MESON, CHRISTMAS };
enum PackTheme THEME;

// ******************* inputs for switches and buttons ******************* //
const int STARTWAND_SWITCH = 6;
const int STARTPACK_SWITCH = 7;
const int MUSIC_SWITCH = 8;
const int FIRE_BUTTON = 4;
const int FIRE_BUTTON2 = 5;
const int VENTING = 9;
const int ISPLAYING_OUT = 12;
const int RUMBLE = 13;

// ******************* Pack states or logic variables ******************* //
bool PowerOff = true;
bool PowerBooted = false;
bool IsFiring = false;
bool shouldWarn = false;
bool shuttingDown = false;
bool warning = false;
bool venting = false;
bool shouldVent = false;
bool IsPlaying = false;

// ******************* physical switch states ******************* //
bool startpack = false;
bool startwand = false;
bool packidle = false;
bool musicmode = false;
bool musicmodestart = false;
bool fire = false;
bool fireButtonState = false;
bool fire2 = false;
bool fire2ButtonState = false;

// ******************* Cyclotron / Powercell timing variables ******************* //
unsigned long prevCycMillis = 0;
unsigned long prevBGMillis = 0;
unsigned long fire_interval = 100;
unsigned long fire_intervalC = 100;
unsigned long FireRate = 0;
unsigned long FireRate2 = 0;

unsigned long cycIdleRate[5] = {1200, 800, 800, 800, 400};

unsigned long firingStateMillis;
unsigned long VentMillis;

const unsigned long firingwarning = 5000;
const unsigned long firingalarm = 10000;
const unsigned long venting_interval = 5000;

/*************************************************************************
                                 SETUP Function
 *************************************************************************/
void setup() {
  
  // ***** Start Communication with the DFPlayer ***** //
  mySoftwareSerial.begin(9600);
  myDFPlayer.begin(mySoftwareSerial);

  myDFPlayer.normalMode();
  myDFPlayer.startDAC();
  myDFPlayer.volume(30);

  
  BarGraph.BGSeq();            // Initiaze the BarGraph               

  // ***** Assign Proton Pack Switches / Buttons ***** //
  pinMode(STARTWAND_SWITCH, INPUT);
  digitalWrite(STARTWAND_SWITCH, HIGH);
  pinMode(STARTPACK_SWITCH, INPUT);
  digitalWrite(STARTPACK_SWITCH, HIGH);
  pinMode(MUSIC_SWITCH, INPUT);
  digitalWrite(MUSIC_SWITCH, HIGH);
  pinMode(FIRE_BUTTON, INPUT);
  digitalWrite(FIRE_BUTTON, HIGH);
  pinMode(FIRE_BUTTON2, INPUT);
  digitalWrite(FIRE_BUTTON2, HIGH);
  pinMode(VENTING, OUTPUT);
  digitalWrite(VENTING, HIGH);
  pinMode(RUMBLE, OUTPUT);
  digitalWrite(RUMBLE, LOW);

  pinMode(ISPLAYING_OUT, INPUT);

  // ***** Configure LED's in wand lights (Including Vent LEDs) ***** //
  wandLights.begin();
  wandLights.setBrightness(240);
  wandLights.show();

  // ***** Configure Proton Pack LED's ***** //
  PackLEDs.begin();
  PackLEDs.Color1 = PackLEDs.Wheel(255);
  PackLEDs.Color2 = PackLEDs.Wheel(170);

  // ***** Set the intial pack status to off ***** //
  STATUS = OFF;
  THEME = MOVIE;
  // ***** Start with LED's off ***** //
  clearLEDs();

  // Add a delay to let the everything initilize
  delay(500);
}

unsigned long CuurentBGInterval = BarGraph.IntervalBG;        // Get the current bargraph interval

/*************************************************************************
                                 Main Loop Function
 *************************************************************************/
void loop()
{
  // put your main code here, to run repeatedly:
  unsigned long currentMillis = millis();

  // Check Wand Switch Status
  startwand = digitalRead(STARTWAND_SWITCH);
  startpack = digitalRead(STARTPACK_SWITCH);
  musicmode = digitalRead(MUSIC_SWITCH);
  fire = digitalRead(FIRE_BUTTON);
  fire2 = digitalRead(FIRE_BUTTON2);
  IsPlaying = digitalRead(ISPLAYING_OUT);

  getWandSTATUS();

  /*
     Switch logic
     Activate Pack - Switch 1
     Active Wand - Switch 2 (Turn Vent On)
     Music - Switch 3 Block Fire Logic, Fire changes song (Pack Must be active)
     Fire 1 / 2 are the same
  */

  /********************************************************************************
      Play / Change music (Fire Button 1) or Change Theme (Fire Button 2)
   ********************************************************************************/
  if (musicmode == true)
  {
    if (fire2 == false &&  fire2ButtonState == false)
    {
      if (STATUS == BOOTED)
      {
        switch (THEME)
        {
          case MOVIE:
            THEME = STASIS;
            PackLEDs.Cyclotron(PackLEDs.Color1, cycIdleRate[1], THEME);
            myDFPlayer.play(ThemeSWTrack);
            break;
          case STASIS:
            THEME = SLIME;
            PackLEDs.Cyclotron(PackLEDs.Color1, cycIdleRate[2], THEME);
            myDFPlayer.play(SlimeSWTrack);
            break;
          case SLIME:
            THEME = MESON;
            PackLEDs.Cyclotron(PackLEDs.Color1, cycIdleRate[3], THEME);
            myDFPlayer.play(MesonSWTrack);
            break;
          case MESON:
            THEME = CHRISTMAS;
            PackLEDs.Cyclotron(PackLEDs.Color1, cycIdleRate[4], THEME);
            myDFPlayer.play(ChristmasSWTrack);
            break;
          case CHRISTMAS:
            THEME = MOVIE;
            PackLEDs.Cyclotron(PackLEDs.Color1, cycIdleRate[0], THEME);
            myDFPlayer.play(ThemeSWTrack);
            break;
        }
      }
      fire2ButtonState = true;
      musicmodestart = false;
    }
    else
    {
      if (fire2 == true)
      {
        fire2ButtonState = false;
      }
    }
    if (fire == false && fireButtonState == false)
    {
      fireButtonState = true;
      if (musicmodestart == false)
      {
        myDFPlayer.playFolder(1, 1);
        musicmodestart = true;
      }
      else
      {
        myDFPlayer.playNext();
      }
    }
    else
    {
      if (fire == true)
      {
        fireButtonState = false;
      }
    }
  }
  else
  {
    musicmodestart = false;
  }
  /********************************************************************************
      Logic routine, Checks for the wand status to activate the pack and wand features
   ********************************************************************************/
  if (WANDSTATUS == ON_PACK) // Turn on the Proton Pack if both the wand activate switch and Pack switch are ON
  {
    // ***** If Booting from a start start the booting routine ***** //
    if (PowerOff == true && startpack == true ) // If fresh poweron
    {
      myDFPlayer.play(StartupTrack);
      BarGraph.initiateVariables(ACTIVE);
      STATUS = BOOTING;
      setVentLightState(ventStart, ventEnd, 2);
      PackLEDs.CyclotronBoot(PackLEDs.Wheel(255), 50,THEME);
      PackLEDs.PowercellBoot(PackLEDs.Wheel(170), 30);
    }
    switch (STATUS)
    {
      case OFF:
        break;
        
      /*
       * Logic routine for booting 
       */
      case BOOTING:
        PowerOff = false;
        BarGraph.sequencePackOn(currentMillis);
        setWandLightState(4, 7, currentMillis); //set sloblow red blinking
        setWandLightState(WhiteLED2, 1, 0);    //  set Wand ON LED white
        break;
      
      /********************************************************************************
         Logic routine for when the pack is fully booted, gun features work
      ********************************************************************************/
      case BOOTED:
        // ***** Based on the pack status and wand status run LED routine ***** //
        WandLightState(currentMillis);
        //Serial.println(WANDLEDSTATUS);
        if (WANDLEDSTATUS == NORMAL)
        {
          BarGraph.sequencePackOn(currentMillis);
        }
        if (IsPlaying == true && musicmode == false && WANDLEDSTATUS == NORMAL)
        {
          myDFPlayer.loop(IdleMovieLoop);
        }
        /*
                        If firing button is pushed, start firing sequence
        */
        fire = digitalRead(FIRE_BUTTON);
        fire2 = digitalRead(FIRE_BUTTON2);
        if ((fire == false && musicmode == false) || (fire2 == false && musicmode == false))
        {
          if (WANDLEDSTATUS != WARNING && WANDLEDSTATUS != FASTWARNING)
          {
            WANDLEDSTATUS = FIRING;
          }
          if (IsFiring == false)
          {
            if (fire2 == false && fire == true && WANDLEDSTATUS != WARNING) 
            {
              if (THEME != MOVIE)
              {
                PlaySoundTrack(FIRING);
              }
              else
              {
                PlaySoundTrack(STREAMCROSS);
              }
              BarGraph.initiateVariables(FIRE2);
              BarGraph.clearLEDs();
            }
            else if ((fire2 == true || fire == false) && WANDLEDSTATUS != WARNING)
            {
              PlaySoundTrack(FIRING);
              BarGraph.initiateVariables(FIRE1);
              BarGraph.clearLEDs();
            }

            firingStateMillis = currentMillis;
            IsFiring = true;
          }
          if (fire2 == false && fire == true)
          {
            setWandLightState(OrangeHatLED, 1, 0); // Set gun button 2 LED white
            BarGraph.sequenceFire2(currentMillis);
            digitalWrite(RUMBLE, HIGH);
          }
          else if (fire == false && fire2 == true)
          {
            BarGraph.sequenceFire1(currentMillis);
            digitalWrite(RUMBLE, HIGH);
          }
          WandFire(currentMillis); // Runs routine to speed up Cyclotron LEDs

          /* 
           * Start Firing timing and at 10 seconds vent pack
           * After 10 seconds start the warning routine 
           */
          if ((millis() - firingStateMillis) >= firingalarm)
          {
            if (WANDLEDSTATUS == WARNING)
            {
              PlaySoundTrack(FASTWARNING);
            }
            WANDLEDSTATUS = FASTWARNING;
            shouldVent = true;
          }
          // After 5 seconds start the alarm routing on the wand
          else if ((millis() - firingStateMillis) >= firingwarning)
          {
            WANDLEDSTATUS = WARNING;
          }

        }
        else // ***** Fire has stopped, Check if venting is required, reset ***** //
        {
          /*
              If you were just firing, reset things back to normal
          */
          // *** Only do this once after firing *** //
          if (IsFiring == true)
          {
            // ** Play tail end firing sound ** //
            if (shouldVent != true)
            {
              PlaySoundTrack(NORMAL);
            }
            // ** Reset Pack LED intervals ** //
            PackLEDs.CyclotronInterval(cycIdleRate[THEME], 0);
            PackLEDs.PowercellInterval(75);

            // ** Turn off firing rumble ** //
            digitalWrite(RUMBLE, LOW);
          }
          IsFiring = false;
          FireRate = 0;
          FireRate2 = 0;
          PackLEDs.cycfadeTimer = 10;
          PackLEDs.cycfadeTimerChange = 10;
          PackLEDs.FadeCyc = 20;
          PackLEDs.FadeCycChange = 20;

          // ** If you should be venting start the ventine routine ** //
          if (shouldVent == true)
          {
            shouldVent = false;
            venting = true;
            VentMillis = currentMillis;
          }
          else if (venting == true)
          {
            /* Venting Routine
               Play the venting track, start the bargraph venting animation, turn on N-Filter LED's.
            */
            if (WANDLEDSTATUS == FASTWARNING)
            {
              myDFPlayer.play(ventTrack);
              BarGraph.initiateVariables(BGVENT);

            }
            WANDLEDSTATUS = VENTSTATE;
            PackLEDs.VentPack();
            BarGraph.sequenceVent(currentMillis);

            // ** Clear venting routine after the venting interval ** //
            if ((currentMillis - VentMillis) >= venting_interval)
            {
              venting = false;
              PowerOff = true;
              WANDLEDSTATUS = NORMAL;
              BarGraph.initiateVariables(ACTIVE);
            }
          }
          else
          {
            // ** If you are not in a normal state, set everything back to normal.
            if (WANDLEDSTATUS != NORMAL && venting == false)
            {
              WANDLEDSTATUS = NORMAL;
              BarGraph.initiateVariables(ACTIVE);
            }
          }
        }
        break;
      case POWERDOWN:
        break;
    }
  }
  else if (WANDSTATUS == ON) // run this if only the wand is ON
  {
    if (STATUS != OFF)
    {
      if (shuttingDown == false)
      {
        BarGraph.clearLEDs();
        BarGraph.initiateVariables(START);
        myDFPlayer.play(shutdownTrack);
        musicmodestart = false;
        STATUS = POWERDOWN;
        shuttingDown = true;
        PackLEDs.PowerDown(100);
      }

    }
    else // ***** If turing wand on from off State play CLICK ***** //
    {
      if (WANDLEDSTATUS != WANDONLY)
      {
        myDFPlayer.play(clickTrack);
        BarGraph.initiateVariables(START);
        musicmodestart = false;
      }
    }
    WANDLEDSTATUS = WANDONLY;
    WandLightState(currentMillis);
    BarGraph.sequenceStart(currentMillis);
  }
  else // IF both the wand switch and pack switch are off
  {
    switch (STATUS)
    {
      case OFF:
        WANDLEDSTATUS = ALLOFF;
        BarGraph.sequenceShutdown(currentMillis);
        WandLightState(currentMillis);
        PackLEDs.PowerDown(100);
        break;
      case BOOTED:
        if (shuttingDown == false)
        {
          BarGraph.IntervalBG = 80;
          myDFPlayer.play(shutdownTrack);
          musicmodestart = false;
          STATUS = POWERDOWN;
          WANDLEDSTATUS = ALLOFF;
          WANDSTATUS = WANDOFF;
          WandLightState(currentMillis);
          shuttingDown = true;
          PackLEDs.PowerDown(100);
        }
        BarGraph.sequenceShutdown(currentMillis);
        break;
      case BOOTING:
        if (shuttingDown == false)
        {
          BarGraph.IntervalBG = 80;
          myDFPlayer.play(shutdownTrack);
          musicmodestart = false;
          STATUS = POWERDOWN;
          WANDLEDSTATUS = ALLOFF;
          WANDSTATUS = WANDOFF;
          WandLightState(currentMillis);
          shuttingDown = true;
          PackLEDs.PowerDown(100);
        }
        BarGraph.sequenceShutdown(currentMillis);
        break;
      case POWERDOWN:
        BarGraph.sequenceShutdown(currentMillis);
        break;
    }
  }
  PackLEDs.Update();
  wandLights.show();
  //delay(1);
}

/*
 * This function speeds up the LED intervals when firing
 */
void WandFire(unsigned long currentMillis)
{
  if ((currentMillis - prevCycMillis) >= fire_interval)
  {
    FireRate++;
    FireRate2 = FireRate2 + cycIdleRate[THEME] / fire_interval;
    prevCycMillis = currentMillis;
    if ( FireRate > 95)
    {
      PackLEDs.PowercellInterval(95 - 94);
    }
    else
    {
      PackLEDs.PowercellInterval(95 - FireRate);
    }
    if ( FireRate2 > (cycIdleRate[THEME] - 30))
    {
      PackLEDs.CyclotronInterval(30, 1);
    }
    else
    {
      PackLEDs.CyclotronInterval((cycIdleRate[THEME] - FireRate2), 1);
    }
  }
  if ((currentMillis - prevBGMillis) >= (CuurentBGInterval * 4.75))
  {
    prevBGMillis = currentMillis;
    if (BarGraph.IntervalBG >= 1)
    {
      BarGraph.changeInterval(BarGraph.IntervalBG - 1);
    }
  }
}

/*
 * Powercell Boot Sequence Completion Callback
 * 
 * This function is called from the library GBLEDPatterns when the boot 
 * sequence or powerdown sequence is completed to change the states of of the pack
 */
  void PackLEDsComplete()
{
  if (STATUS == BOOTING)
  {
    STATUS = BOOTED;
    WANDLEDSTATUS = NORMAL;
    PowerBooted = true;
    PackLEDs.Cyclotron(PackLEDs.Color1, cycIdleRate[THEME], THEME);
    PackLEDs.PowercellClear();
    PackLEDs.Powercell(PackLEDs.Color2, 75);
    //setWandLightState(4, 0, 0); //set sloblow red
  }
  else if (STATUS == POWERDOWN)
  {
    PowerOff = true;
    shuttingDown = false;
    PowerBooted = false;
    PackLEDs.Color1 = PackLEDs.Wheel(0);
    PackLEDs.Color2 = PackLEDs.Wheel(0);
    PackLEDs.ActivePattern1 =  NONE;
    PackLEDs.ActivePattern2 =  NONE;
    clearLEDs();
    STATUS = OFF;
    if (WANDSTATUS == WANDOFF)
    {
      THEME = MOVIE;
    }

  }
}
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

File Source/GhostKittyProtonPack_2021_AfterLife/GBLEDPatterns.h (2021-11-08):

/****************************************************************************************
   Michael Simone - Arduino Source for 2020 Ghostbusters Proton Pack
   This is a modified Adafruit library to handle the routine operations for both the Cyclotron and Powercell.
   The following are the pattern types supported:


*/
enum  pattern { NONE, POWERCELL, POWERCELL_BOOT, CYCLOTRON, CYCLOTRON_BOOT, POWERDOWNPACK, VENT };
// Patern directions supported:
enum  direction { FORWARD, REVERSE };

// NeoPattern Class - derived from the Adafruit_NeoPixel class
class NeoPatterns : public Adafruit_NeoPixel
{
  public:

    // *** Pattern variables for both the Cyclotron and Powercell
    pattern  ActivePattern1;        // which Cycltron pattern is running
    pattern  ActivePattern2;        // which Powercell pattern is running

    direction Direction;            // direction to run the pattern

    /*
       The following are interval variables to manage timing and the change of timing during firing
    */

    unsigned long Interval;         // Cyclotron milliseconds between updates (These are set in the main program)
    unsigned long IntervalChange;
    unsigned long Interval2;        // Cyclotron milliseconds between updates (These are set in the main program)
    unsigned long lastUpdateC;      // last update of position
    unsigned long lastUpdatePC;     // last update of position
    uint8_t themeMode;

    // Added these variables to handle the change in fading speeds when firing
    bool fadeComplete = false;
    bool IntervalChangeFlag = false;
    bool AfterLifeFiring = false;
    uint8_t mytime;

    /*
       The following provide an index position of the LED's to determine which one you want to change in the loop sequence
    */

    uint16_t IndexC;                // current step within the pattern (Cyclotron)
    uint8_t  IndexPC;               // current step within the pattern (PowerCell)

    uint16_t TotalStepsC;           // total number of steps in the Cyclotron pattern
    uint16_t TotalStepsPC;          // total number of steps in the PowerCell pattern

    uint32_t Color1, Color2;        // What colors are in use
    int fadeStep = 0;               // state variable for fade function
    uint16_t PCSegIndex;            //

    /*
       Cyclotron & Powercell references
    */

    const uint8_t CyclotronLEDs = 40;
    const uint8_t PowerCellLEDs = 16;

    uint16_t IndexCLEDArray;
    const uint8_t   NUM_LEDS = 40;
    const uint8_t  CyclotronLEDCount = 40;
    const int CyclotronLEDArray[40] = {1, 1, 1, 1, 1, 1, 1, 1, 1, 1, 1, 1, 1, 1, 1, 1, 1, 1, 1, 1, 1, 1, 1, 1, 1, 1, 1, 1, 1, 1, 1, 1, 1, 1, 1, 1, 1, 1, 1, 1};
    /*
        CYCLOTRON LED Pattern (Note: LED reference will still be 0-19, timing will reference 31 spots)
        0 - 4 LED (Lower right Cyclotron Lens)
        5 BLANK (No LED's)
        6-10 LED  (Lower left Cyclotron Lens)
        11-13 BLANK (No LED's)
        14 - 18 LED (Upper left Cyclotron Lens)
        19 - 22 BLANK (No LED's)
        23 - 27 LED (Upper right Cyclotron Lens)
        28-30 BLANK (No LED's)
    */

    bool cycNormalStart = false;      // Used on the first routine to clear all LEDs before you start the sequence

    /*
       Call back functions to let you know when a routine is complete E.g. let you know when the pack is powered up or down.
    */

    void (*OnCompleteC)();  // Callback on completion of pattern
    void (*OnCompletePC)();  // Callback on completion of pattern

    // Constructor - calls base-class constructor to initialize strip
    NeoPatterns(uint16_t pixels, uint8_t pin, uint8_t type, void (*callback)())
      : Adafruit_NeoPixel(pixels, pin, type)
    {
      //OnCompleteC = callback;
      OnCompletePC = callback;
    }

    /*
        Main Update that gets called to refresh all your LED's, this checks the routine
        and calls the appropriate updates.
    */
    void Update()
    {
      //CyclotronUpdate();

      if ((millis() - lastUpdateC) > Interval) // Time to update Cyclotron ?
      {
        lastUpdateC = millis();
        switch (ActivePattern1)
        {
          case CYCLOTRON:
            CyclotronUpdate();
            break;
          case CYCLOTRON_BOOT:
            CyclotronBootUpdate();
            break;
          case VENT:
            break;
          case POWERDOWNPACK:
            break;
          default:
            break;
        }
      }
      if ((millis() - lastUpdatePC) > Interval2) // Time to update Cyclotron PowerCell?
      {
        lastUpdatePC = millis();
        switch (ActivePattern2)
        {
          case POWERCELL:
            PowercellUpdate();
            break;
          case POWERCELL_BOOT:
            PowercellBootUpdate();
            break;
          case POWERDOWNPACK:
            PowerDownUpdate();
            break;
          case VENT:
            VentPackUpdate();
          default:
            break;
        }
      }
    }

    /*
       Increment the cyclotron state (4 states, called after every interval)
    */
    void IncrementC()
    {
      if (ActivePattern1 == CYCLOTRON)
      {
        if (CyclotronLEDArray[IndexC] == 1)
        {
          IndexCLEDArray++;
        }
        IndexC++;
        if (IndexC >= TotalStepsC)
        {
          IndexC = 0;
          IndexCLEDArray = 0;
          if (themeMode == 4)
          {
            if (Color1 == Wheel(255))
            {
              Color1 = Wheel(85);
            }
            else
            {
              Color1 = Wheel(255);
            }
          }
          if (OnCompleteC != NULL)
          {

            OnCompleteC(); // call the completion callback
          }
        }
      }
    }
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

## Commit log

2020-09-25 Untested PCBs
    [GBWand.brd, GBWand.sch, Ghostbusters.brd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]
2021-11-08 Added Afterlife Source
    Added Afterlife Source
    Updated PCB, Ethernet port connector now on wand
    [GBWand.sch, GBWandR1.brd, GBWandR1.sch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]

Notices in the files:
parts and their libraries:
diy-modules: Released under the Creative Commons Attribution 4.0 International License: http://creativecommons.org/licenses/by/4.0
